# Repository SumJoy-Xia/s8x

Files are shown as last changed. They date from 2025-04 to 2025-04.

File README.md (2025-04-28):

# s8x
open source H87/H88 and infinite875 PCB made by sumjoy
开源H87/H88和infinite875 PCB

kicad preview
kicad预览图




firmware to be updated, stay tuned
固件后续更新

PYG.step is the step file of PCB which represents the 3d model of PCB
in case u need it for drawing keyboard cases
PYG.step是PCB的模型
为了方便大家画键盘

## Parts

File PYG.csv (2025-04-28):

Reference | Value | Footprint
C1,C7 | 10uF | Capacitor_SMD:C_0805_2012Metric
C2,C3,C4,C5,C6 | 100nF | Capacitor_SMD:C_0805_2012Metric
C8 | 0.1uF | Capacitor_SMD:C_0805_2012Metric
D1,D2,D3,D4,D5,D6,D7,D8,D9,D10,D11,D12,D13,D14,D15,D16,D17,D18,D19,D20,D21,D22,D23,D24,D25,D26,D27,D28,D29,D30,D31,D32,D33,D34,D35,D36,D37,D38,D39,D40,D41,D42,D43,D44,D45,D46,D47,D48,D49,D50,D51,D52,D53,D54,D55,D56,D57,D58,D59,D60,D61,D62,D63,D64,D65,D66,D67,D68,D69,D70,D71,D72,D73,D74,D75,D76,D77,D78,D79,D80,D81,D82,D83,D84,D85,D86,D87,D88,D89,D90,D91,D92 | D_Small | Diode_SMD:D_0805_2012Metric
F1 | 500mA | Fuse:Fuse_1206_3216Metric
J1 | Conn_01x04 | Connector_JST:JST_SH_SM04B-SRSS-TB_1x04-1MP_P1.00mm_Horizontal
J3 | USB_C_Receptacle_USB2.0 | Connector_USB:USB_C_Receptacle_HRO_TYPE-C-31-M-12
R1,R4 | 10k | Resistor_SMD:R_0805_2012Metric
R2,R3 | 5.1k | Resistor_SMD:R_0805_2012Metric
R5,R6 | 1k | Resistor_SMD:R_0805_2012Metric
RESET1 | SW_SPST | Button_Switch_SMD:SW_SPST_TL3342
U1 | STM32F072CBT6 | Package_QFP:LQFP-48_7x7mm_P0.5mm
U2 | PRTR5V0U2X | Package_TO_SOT_SMD:SOT-143
U3 | XC6206PxxxMR-Regulator_Linear | Package_TO_SOT_SMD:SOT-23

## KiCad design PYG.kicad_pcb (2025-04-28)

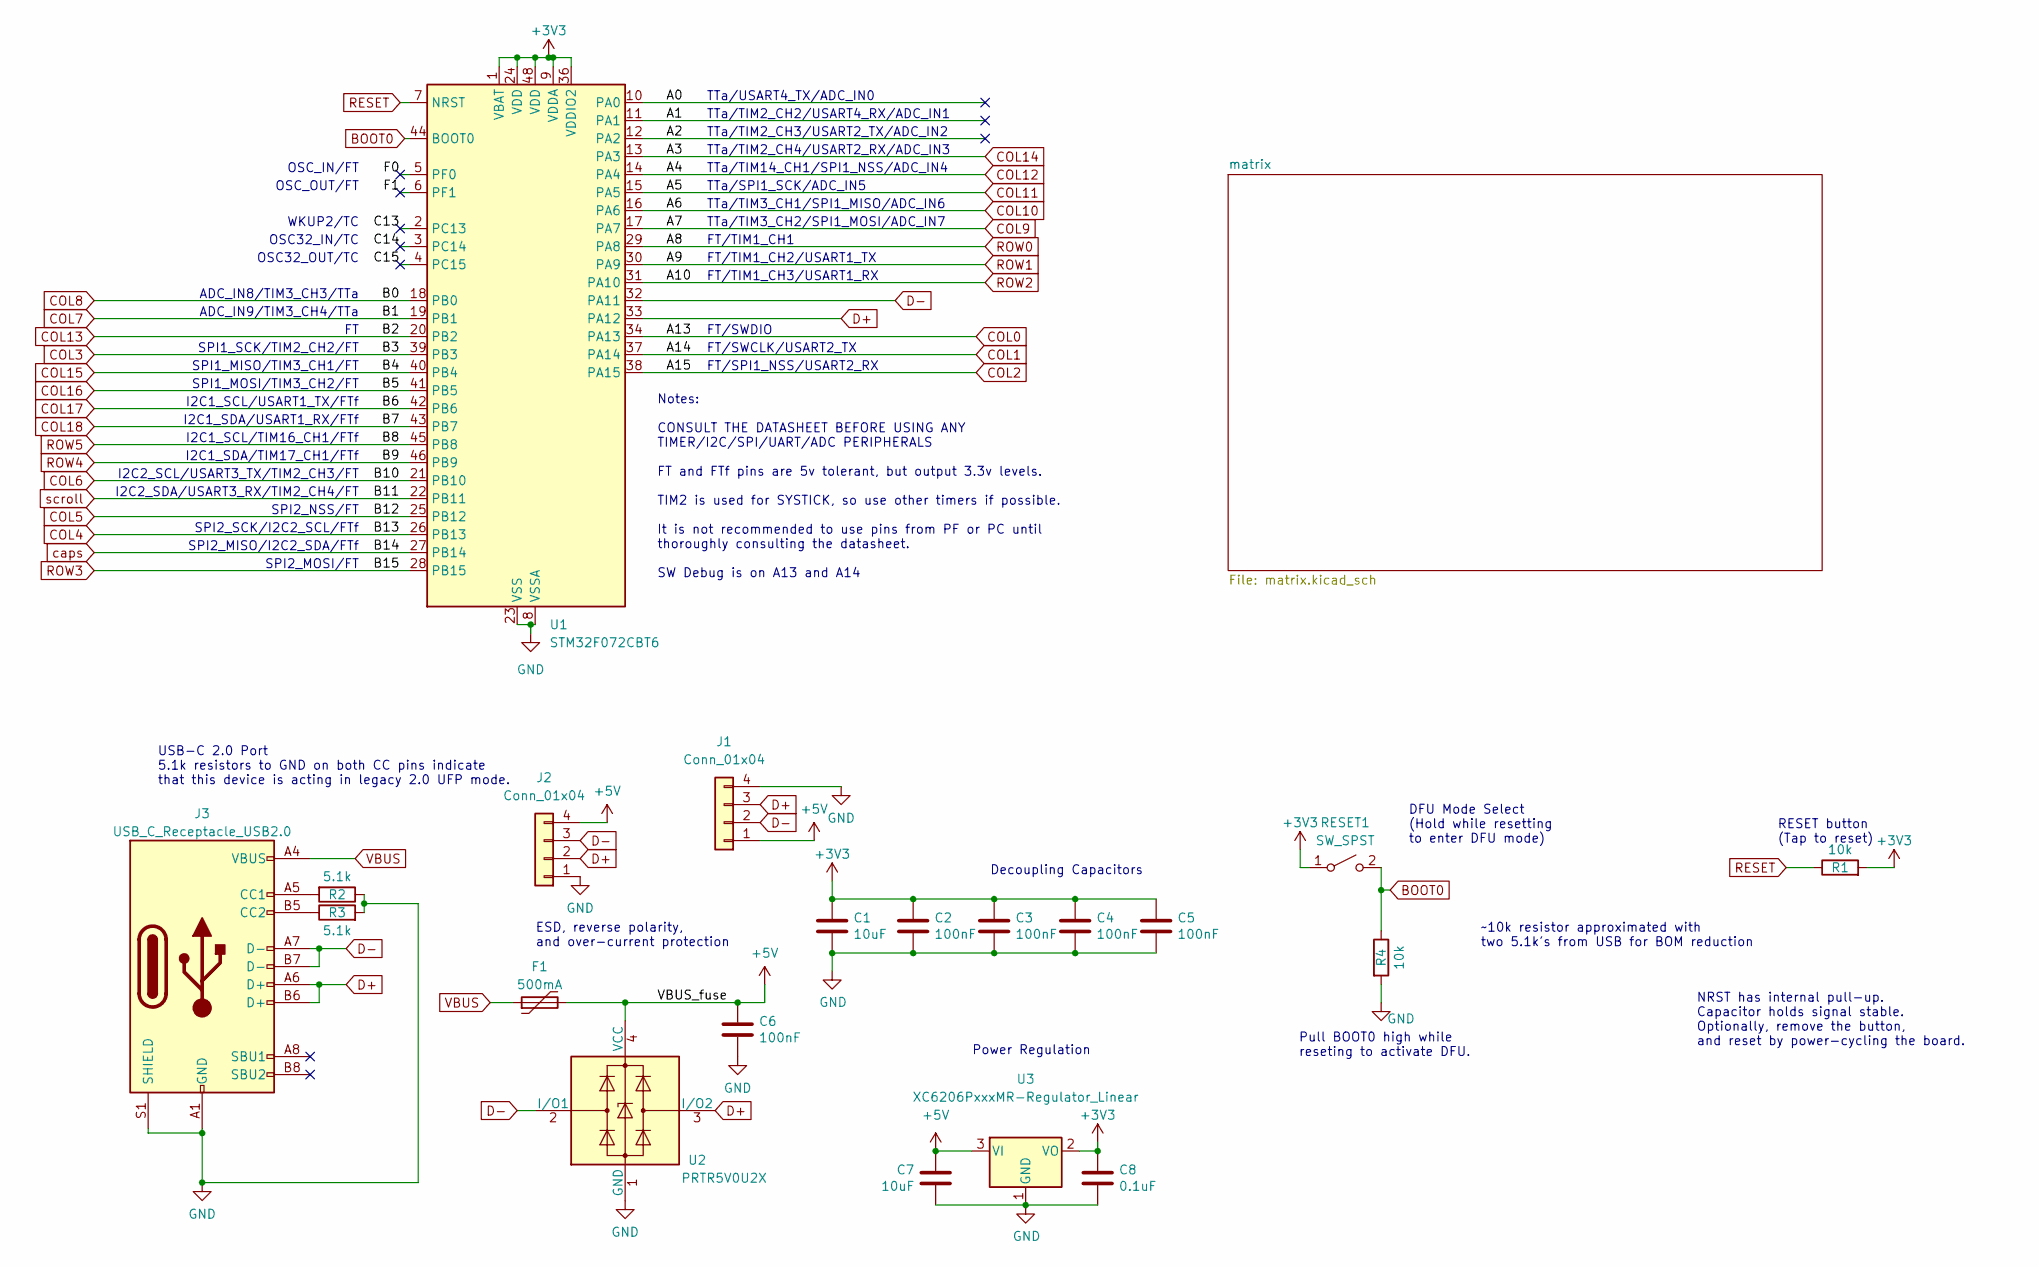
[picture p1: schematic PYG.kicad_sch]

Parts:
C1, C7: 10uF; C_0805_2012Metric; LCSC C307331
C2, C3, C4, C5, C6: 100nF; C_0805_2012Metric; LCSC C307331
C8: 0.1uF; C_0805_2012Metric; LCSC C307331
F1: 500mA; Fuse_1206_3216Metric; LCSC C135341
J1: Conn_01x04; JST_SH_SM04B-SRSS-TB_1x04-1MP_P1.00mm_Horizontal
J2: Conn_01x04; PinHeader_1x04_P2.54mm_Vertical
J3: USB_C_Receptacle_USB2.0; USB_C_Receptacle_HRO_TYPE-C-31-M-12; JlcRotOffset 180
R1, R4: 10k; R_0805_2012Metric
R2, R3: 5.1k; R_0805_2012Metric
RESET1: SW_SPST; SW_SPST_TL3342
U1: STM32F072CBT6; LQFP-48_7x7mm_P0.5mm; JlcRotOffset 90
U2: PRTR5V0U2X; SOT-143; LCSC C2827688
U3: XC6206PxxxMR-Regulator_Linear; SOT-23; LCSC C5446

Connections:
+3V3: C1.1, C2.1, C3.1, C4.1, C5.1, C8.1, R1.2, RESET1.1 (A), U1.1 (VBAT), U1.9 (VDDA), U1.24 (VDD), U1.36 (VDDIO2), U1.48 (VDD), U3.2 (VO)
+5V: C6.1, C7.1, F1.2, J1.1, J2.4, U2.4 (VCC), U3.3 (VI); also elsewhere on the board
/A0: U1.10 (PA0)
/A1: U1.11 (PA1)
/A2: U1.12 (PA2)
/C13: U1.2 (PC13)
/C14: U1.3 (PC14)
/C15: U1.4 (PC15)
/F0: U1.5 (PF0)
/F1: U1.6 (PF1)
BOOT0: R4.1, RESET1.2 (B), U1.44 (BOOT0)
COL0: U1.34 (PA13); also elsewhere on the board
COL1: U1.37 (PA14); also elsewhere on the board
COL2: U1.38 (PA15); also elsewhere on the board
COL3: U1.39 (PB3); also elsewhere on the board
COL4: U1.26 (PB13); also elsewhere on the board
COL5: U1.25 (PB12); also elsewhere on the board
COL6: U1.21 (PB10); also elsewhere on the board
COL7: U1.19 (PB1); also elsewhere on the board
COL8: U1.18 (PB0); also elsewhere on the board
COL9: U1.17 (PA7); also elsewhere on the board
COL10: U1.16 (PA6); also elsewhere on the board
COL11: U1.15 (PA5); also elsewhere on the board
COL12: U1.14 (PA4); also elsewhere on the board
COL13: U1.20 (PB2); also elsewhere on the board
COL14: U1.13 (PA3); also elsewhere on the board
COL15: U1.40 (PB4); also elsewhere on the board
COL16: U1.41 (PB5); also elsewhere on the board
COL17: U1.42 (PB6); also elsewhere on the board
COL18: U1.43 (PB7); also elsewhere on the board
D+: J1.3, J2.2, J3.A6 (D+), J3.B6 (D+), U1.33 (PA12), U2.3 (I/O2)
D-: J1.2, J2.3, J3.A7 (D-), J3.B7 (D-), U1.32 (PA11), U2.2 (I/O1)
GND: C1.2, C2.2, C3.2, C4.2, C5.2, C6.2, C7.2, C8.2, J1.4, J2.1, J3.A1 (GND), J3.A12 (GND), J3.B1 (GND), J3.B12 (GND), J3.S1 (SHIELD), R2.1, R3.2, R4.2, U1.8 (VSSA), U1.23 (VSS), U1.35 (VSS), U1.47 (VSS), U2.1 (GND), U3.1 (GND)
unnamed: J3.A5 (CC1), R2.2
unnamed: J3.B5 (CC2), R3.1
RESET: R1.1, U1.7 (NRST)
ROW0: U1.29 (PA8); also elsewhere on the board
ROW1: U1.30 (PA9); also elsewhere on the board
ROW2: U1.31 (PA10); also elsewhere on the board
ROW3: U1.28 (PB15); also elsewhere on the board
ROW4: U1.46 (PB9); also elsewhere on the board
ROW5: U1.45 (PB8); also elsewhere on the board
VBUS: F1.1, J3.A4 (VBUS), J3.A9 (VBUS), J3.B4 (VBUS), J3.B9 (VBUS)
caps: U1.27 (PB14); also elsewhere on the board
scroll: U1.22 (PB11); also elsewhere on the board

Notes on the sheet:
SPI1_SCK/TIM2_CH2/FT
SPI2_MISO/I2C2_SDA/FTf
SPI1_MOSI/TIM3_CH2/FT
Notes: CONSULT THE DATASHEET BEFORE USING ANY TIMER/I2C/SPI/UART/ADC PERIPHERALS FT and FTf pins are 5v tolerant, but output 3.3v levels. TIM2 is used for SYSTICK, so use other timers if possible. It is not recommended to use pins from PF or PC until thoroughly consulting the datasheet. SW Debug is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
TTa/TIM3_CH2/SPI1_MOSI/ADC_IN7
FT/TIM1_CH3/USART1_RX
SPI2_MOSI/FT
I2C1_SDA/USART1_RX/FTf
FT/TIM1_CH1
OSC32_OUT/TC
I2C2_SDA/USART3_RX/TIM2_CH4/FT
SPI2_SCK/I2C2_SCL/FTf
OSC_OUT/FT
SPI2_NSS/FT
TTa/TIM3_CH1/SPI1_MISO/ADC_IN6
SPI1_MISO/TIM3_CH1/FT
I2C1_SDA/TIM17_CH1/FTf
I2C2_SCL/USART3_TX/TIM2_CH3/FT
I2C1_SCL/TIM16_CH1/FTf
ADC_IN8/TIM3_CH3/TTa
WKUP2/TC
TTa/TIM2_CH3/USART2_TX/ADC_IN2
TTa/TIM14_CH1/SPI1_NSS/ADC_IN4
NRST has internal pull-up. Capacitor holds signal stable. Optionally, remove the button, and reset by power-cycling the board.
DFU Mode Select (Hold while resetting to enter DFU mode)
ESD, reverse polarity, and over-current protection
FT/SPI1_NSS/USART2_RX
~10k resistor approximated with two 5.1k's from USB for BOM reduction
FT/SWDIO
TTa/TIM2_CH4/USART2_RX/ADC_IN3
TTa/USART4_TX/ADC_IN0
USB-C 2.0 Port 5.1k resistors to GND on both CC pins indicate that this device is acting in legacy 2.0 UFP mode.
RESET button (Tap to reset)
ADC_IN9/TIM3_CH4/TTa
TTa/SPI1_SCK/ADC_IN5
FT/TIM1_CH2/USART1_TX
Power Regulation
OSC_IN/FT
TTa/TIM2_CH2/USART4_RX/ADC_IN1
Decoupling Capacitors

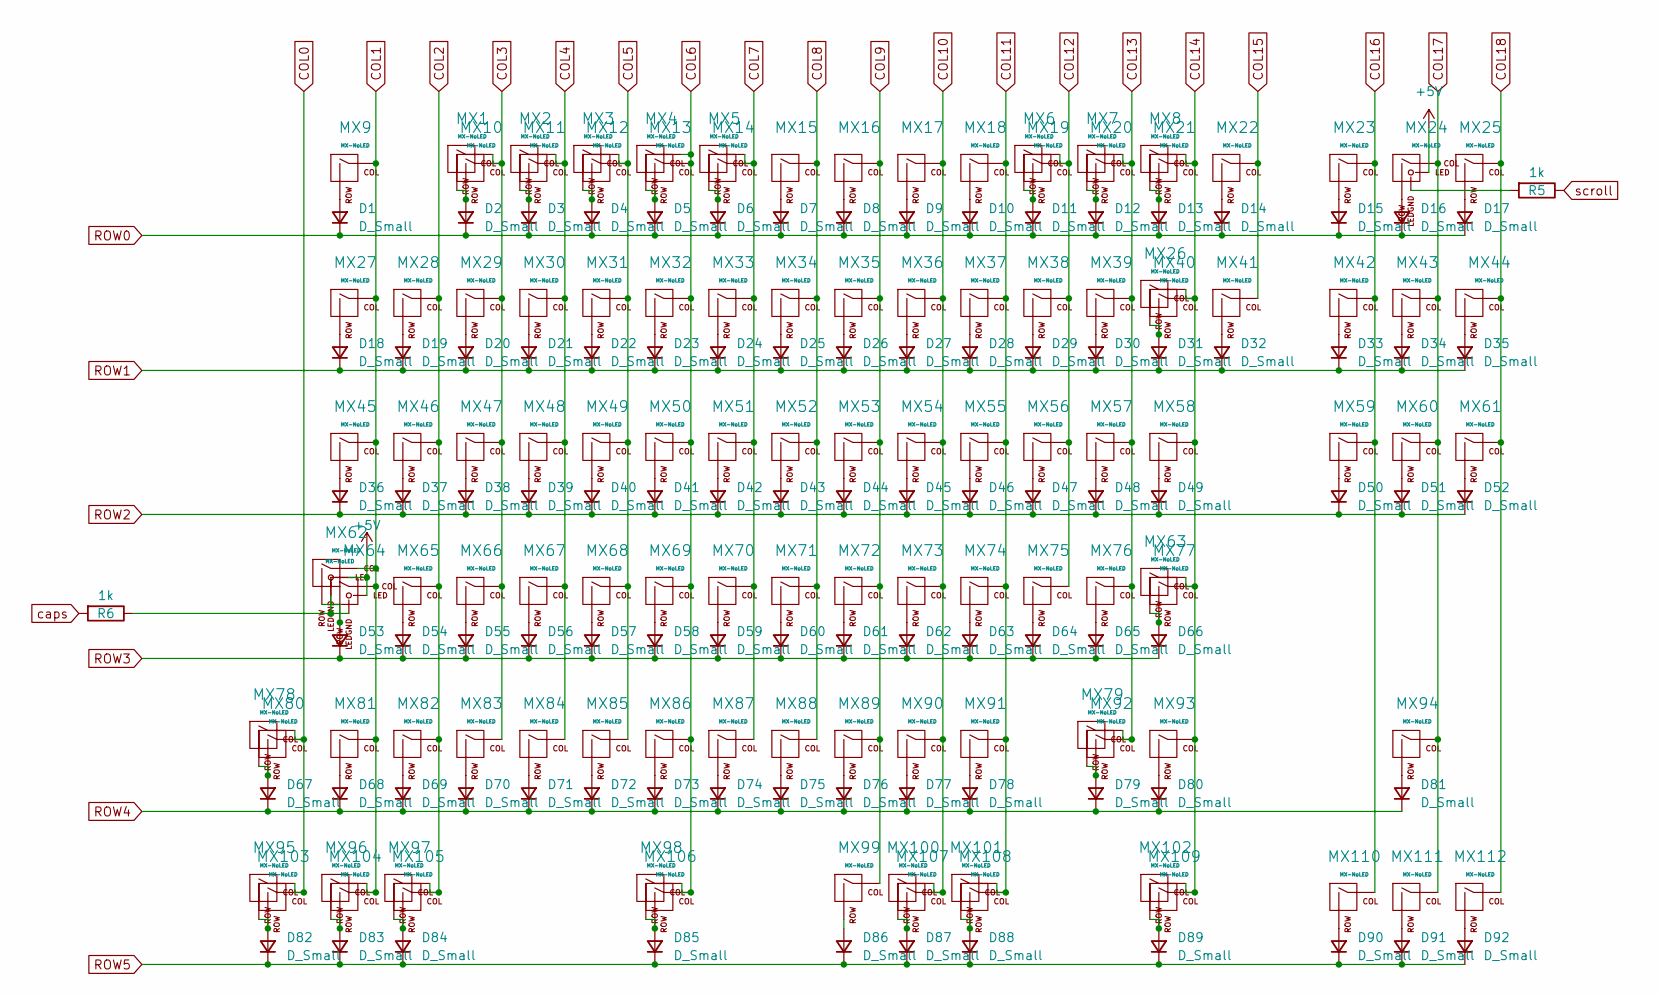
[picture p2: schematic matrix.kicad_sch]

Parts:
D1, D2, D3, D4, D5, D6, D7, D8, D9, D10, D11, D12, D13, D14, D15, D16, D17, D18, D19, D20, D21, D22, D23, D24, D25, D26, D27, D28, D29, D30, D31, D32, D33, D34, D35, D36, D37, D38, D39, D40, D41, D42, D43, D44, D45, D46, D47, D48, D49, D50, D51, D52, D53, D54, D55, D56, D57, D58, D59, D60, D61, D62, D63, D64, D65, D66, D67, D68, D69, D70, D71, D72, D73, D74, D75, D76, D77, D78, D79, D80, D81, D82, D83, D84, D85, D86, D87, D88, D89, D90, D91, D92: D_Small; D_0805_2012Metric
MX1, MX2, MX3, MX4, MX5, MX6, MX7, MX8, MX9, MX10, MX11, MX12, MX13, MX14, MX15, MX16, MX17, MX18, MX19, MX20, MX21, MX22, MX23, MX25, MX26, MX27, MX28, MX29, MX30, MX31, MX32, MX33, MX34, MX35, MX36, MX37, MX38, MX39, MX41, MX42, MX43, MX44, MX46, MX47, MX48, MX49, MX50, MX51, MX52, MX53, MX54, MX55, MX56, MX57, MX59, MX60, MX61, MX65, MX66, MX67, MX68, MX69, MX70, MX71, MX72, MX73, MX74, MX75, MX76, MX81, MX82, MX83, MX84, MX85, MX86, MX87, MX88, MX89, MX90, MX91, MX93, MX94, MX104, MX108, MX110, MX111, MX112: MX-NoLED; MXOnly-1U-NoLED
MX24: MX-NoLED; MXOnly-1U
MX40: MX-NoLED; MXOnly-2U-NoLED
MX45, MX58, MX103, MX105, MX107, MX109: MX-NoLED; MXOnly-1.5U-NoLED
MX62: MX-NoLED; MXOnly-1.75U-FLIPPED
MX63: MX-NoLED; MXOnly-ISO-ReversedStabilizers-NoLED
MX64: MX-NoLED; MXOnly-1.75U-STEP1.25
MX77, MX80: MX-NoLED; MXOnly-2.25U-NoLED
MX78, MX95, MX96, MX97, MX99, MX100, MX101, MX102: MX-NoLED; MXOnly-1.25U-NoLED
MX79: MX-NoLED; MXOnly-1.75U-NoLED
MX92: MX-NoLED; MXOnly-2.75U-NoLED
MX98: MX-NoLED; MXOnly-6.25U-ReversedStabilizers-NoLED
MX106: MX-NoLED; MXOnly-7U-ReversedStabilizers-NoLED
R5, R6: 1k; R_0805_2012Metric

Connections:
+5V: MX24.3 (LED), MX62.3 (LED), MX64.3 (LED); also elsewhere on the board
COL0: MX78.1 (COL), MX80.1 (COL), MX95.1 (COL), MX103.1 (COL); also elsewhere on the board
COL1: MX9.1 (COL), MX27.1 (COL), MX45.1 (COL), MX62.1 (COL), MX64.1 (COL), MX81.1 (COL), MX96.1 (COL), MX104.1 (COL); also elsewhere on the board
COL2: MX28.1 (COL), MX46.1 (COL), MX65.1 (COL), MX82.1 (COL), MX97.1 (COL), MX105.1 (COL); also elsewhere on the board
COL3: MX1.1 (COL), MX10.1 (COL), MX29.1 (COL), MX47.1 (COL), MX66.1 (COL), MX83.1 (COL); also elsewhere on the board
COL4: MX2.1 (COL), MX11.1 (COL), MX30.1 (COL), MX48.1 (COL), MX67.1 (COL), MX84.1 (COL); also elsewhere on the board
COL5: MX3.1 (COL), MX12.1 (COL), MX31.1 (COL), MX49.1 (COL), MX68.1 (COL), MX85.1 (COL); also elsewhere on the board
COL6: MX4.1 (COL), MX13.1 (COL), MX32.1 (COL), MX50.1 (COL), MX69.1 (COL), MX86.1 (COL), MX98.1 (COL), MX106.1 (COL); also elsewhere on the board
COL7: MX5.1 (COL), MX14.1 (COL), MX33.1 (COL), MX51.1 (COL), MX70.1 (COL), MX87.1 (COL); also elsewhere on the board
COL8: MX15.1 (COL), MX34.1 (COL), MX52.1 (COL), MX71.1 (COL), MX88.1 (COL); also elsewhere on the board
COL9: MX16.1 (COL), MX35.1 (COL), MX53.1 (COL), MX72.1 (COL), MX89.1 (COL), MX99.1 (COL); also elsewhere on the board
COL10: MX17.1 (COL), MX36.1 (COL), MX54.1 (COL), MX73.1 (COL), MX90.1 (COL), MX100.1 (COL), MX107.1 (COL); also elsewhere on the board
COL11: MX18.1 (COL), MX37.1 (COL), MX55.1 (COL), MX74.1 (COL), MX91.1 (COL), MX101.1 (COL), MX108.1 (COL); also elsewhere on the board
COL12: MX6.1 (COL), MX19.1 (COL), MX38.1 (COL), MX56.1 (COL), MX75.1 (COL); also elsewhere on the board
COL13: MX7.1 (COL), MX20.1 (COL), MX39.1 (COL), MX57.1 (COL), MX76.1 (COL), MX79.1 (COL), MX92.1 (COL); also elsewhere on the board
COL14: MX8.1 (COL), MX21.1 (COL), MX26.1 (COL), MX40.1 (COL), MX58.1 (COL), MX63.1 (COL), MX77.1 (COL), MX93.1 (COL), MX102.1 (COL), MX109.1 (COL); also elsewhere on the board
COL15: MX22.1 (COL), MX41.1 (COL); also elsewhere on the board
COL16: MX23.1 (COL), MX42.1 (COL), MX59.1 (COL), MX110.1 (COL); also elsewhere on the board
COL17: MX24.1 (COL), MX43.1 (COL), MX60.1 (COL), MX94.1 (COL), MX111.1 (COL); also elsewhere on the board
COL18: MX25.1 (COL), MX44.1 (COL), MX61.1 (COL), MX112.1 (COL); also elsewhere on the board
unnamed: D1.2 (A), MX9.2 (ROW)
unnamed: D2.2 (A), MX1.2 (ROW), MX10.2 (ROW)
unnamed: D3.2 (A), MX2.2 (ROW), MX11.2 (ROW)
unnamed: D4.2 (A), MX3.2 (ROW), MX12.2 (ROW)
unnamed: D5.2 (A), MX4.2 (ROW), MX13.2 (ROW)
unnamed: D6.2 (A), MX5.2 (ROW), MX14.2 (ROW)
unnamed: D7.2 (A), MX15.2 (ROW)
unnamed: D8.2 (A), MX16.2 (ROW)
unnamed: D9.2 (A), MX17.2 (ROW)
unnamed: D10.2 (A), MX18.2 (ROW)
unnamed: D11.2 (A), MX6.2 (ROW), MX19.2 (ROW)
unnamed: D12.2 (A), MX7.2 (ROW), MX20.2 (ROW)
unnamed: D13.2 (A), MX8.2 (ROW), MX21.2 (ROW)
unnamed: D14.2 (A), MX22.2 (ROW)
unnamed: D15.2 (A), MX23.2 (ROW)
unnamed: D16.2 (A), MX24.2 (ROW)
unnamed: D17.2 (A), MX25.2 (ROW)
unnamed: D18.2 (A), MX27.2 (ROW)
unnamed: D19.2 (A), MX28.2 (ROW)
unnamed: D20.2 (A), MX29.2 (ROW)
unnamed: D21.2 (A), MX30.2 (ROW)
unnamed: D22.2 (A), MX31.2 (ROW)
unnamed: D23.2 (A), MX32.2 (ROW)
unnamed: D24.2 (A), MX33.2 (ROW)
unnamed: D25.2 (A), MX34.2 (ROW)
unnamed: D26.2 (A), MX35.2 (ROW)
unnamed: D27.2 (A), MX36.2 (ROW)
unnamed: D28.2 (A), MX37.2 (ROW)
unnamed: D29.2 (A), MX38.2 (ROW)
unnamed: D30.2 (A), MX39.2 (ROW)
unnamed: D31.2 (A), MX26.2 (ROW), MX40.2 (ROW)
unnamed: D32.2 (A), MX41.2 (ROW)
unnamed: D33.2 (A), MX42.2 (ROW)
unnamed: D34.2 (A), MX43.2 (ROW)
unnamed: D35.2 (A), MX44.2 (ROW)
unnamed: D36.2 (A), MX45.2 (ROW)
unnamed: D37.2 (A), MX46.2 (ROW)
unnamed: D38.2 (A), MX47.2 (ROW)
unnamed: D39.2 (A), MX48.2 (ROW)
unnamed: D40.2 (A), MX49.2 (ROW)
unnamed: D41.2 (A), MX50.2 (ROW)
unnamed: D42.2 (A), MX51.2 (ROW)
unnamed: D43.2 (A), MX52.2 (ROW)
unnamed: D44.2 (A), MX53.2 (ROW)
unnamed: D45.2 (A), MX54.2 (ROW)
unnamed: D46.2 (A), MX55.2 (ROW)
unnamed: D47.2 (A), MX56.2 (ROW)
unnamed: D48.2 (A), MX57.2 (ROW)
unnamed: D49.2 (A), MX58.2 (ROW)
unnamed: D50.2 (A), MX59.2 (ROW)
unnamed: D51.2 (A), MX60.2 (ROW)
unnamed: D52.2 (A), MX61.2 (ROW)
unnamed: D53.2 (A), MX62.2 (ROW), MX64.2 (ROW)
unnamed: D54.2 (A), MX65.2 (ROW)
unnamed: D55.2 (A), MX66.2 (ROW)
unnamed: D56.2 (A), MX67.2 (ROW)
unnamed: D57.2 (A), MX68.2 (ROW)
unnamed: D58.2 (A), MX69.2 (ROW)
unnamed: D59.2 (A), MX70.2 (ROW)
unnamed: D60.2 (A), MX71.2 (ROW)
unnamed: D61.2 (A), MX72.2 (ROW)
unnamed: D62.2 (A), MX73.2 (ROW)
unnamed: D63.2 (A), MX74.2 (ROW)
unnamed: D64.2 (A), MX75.2 (ROW)
unnamed: D65.2 (A), MX76.2 (ROW)
unnamed: D66.2 (A), MX63.2 (ROW), MX77.2 (ROW)
unnamed: D67.2 (A), MX78.2 (ROW), MX80.2 (ROW)
unnamed: D68.2 (A), MX81.2 (ROW)
unnamed: D69.2 (A), MX82.2 (ROW)
unnamed: D70.2 (A), MX83.2 (ROW)
unnamed: D71.2 (A), MX84.2 (ROW)
unnamed: D72.2 (A), MX85.2 (ROW)
unnamed: D73.2 (A), MX86.2 (ROW)
unnamed: D74.2 (A), MX87.2 (ROW)
unnamed: D75.2 (A), MX88.2 (ROW)
unnamed: D76.2 (A), MX89.2 (ROW)
unnamed: D77.2 (A), MX90.2 (ROW)
unnamed: D78.2 (A), MX91.2 (ROW)
unnamed: D79.2 (A), MX79.2 (ROW), MX92.2 (ROW)
unnamed: D80.2 (A), MX93.2 (ROW)
unnamed: D81.2 (A), MX94.2 (ROW)
unnamed: D82.2 (A), MX95.2 (ROW), MX103.2 (ROW)
unnamed: D83.2 (A), MX96.2 (ROW), MX104.2 (ROW)
unnamed: D84.2 (A), MX97.2 (ROW), MX105.2 (ROW)
unnamed: D85.2 (A), MX98.2 (ROW), MX106.2 (ROW)
unnamed: D86.2 (A), MX99.2 (ROW)
unnamed: D87.2 (A), MX100.2 (ROW), MX107.2 (ROW)
unnamed: D88.2 (A), MX101.2 (ROW), MX108.2 (ROW)
unnamed: D89.2 (A), MX102.2 (ROW), MX109.2 (ROW)
unnamed: D90.2 (A), MX110.2 (ROW)
unnamed: D91.2 (A), MX111.2 (ROW)
unnamed: D92.2 (A), MX112.2 (ROW)
unnamed: MX24.4 (LEDGND), R5.2
unnamed: MX62.4 (LEDGND), MX64.4 (LEDGND), R6.1
ROW0: D1.1 (K), D2.1 (K), D3.1 (K), D4.1 (K), D5.1 (K), D6.1 (K), D7.1 (K), D8.1 (K), D9.1 (K), D10.1 (K), D11.1 (K), D12.1 (K), D13.1 (K), D14.1 (K), D15.1 (K), D16.1 (K), D17.1 (K); also elsewhere on the board
ROW1: D18.1 (K), D19.1 (K), D20.1 (K), D21.1 (K), D22.1 (K), D23.1 (K), D24.1 (K), D25.1 (K), D26.1 (K), D27.1 (K), D28.1 (K), D29.1 (K), D30.1 (K), D31.1 (K), D32.1 (K), D33.1 (K), D34.1 (K), D35.1 (K); also elsewhere on the board
ROW2: D36.1 (K), D37.1 (K), D38.1 (K), D39.1 (K), D40.1 (K), D41.1 (K), D42.1 (K), D43.1 (K), D44.1 (K), D45.1 (K), D46.1 (K), D47.1 (K), D48.1 (K), D49.1 (K), D50.1 (K), D51.1 (K), D52.1 (K); also elsewhere on the board
ROW3: D53.1 (K), D54.1 (K), D55.1 (K), D56.1 (K), D57.1 (K), D58.1 (K), D59.1 (K), D60.1 (K), D61.1 (K), D62.1 (K), D63.1 (K), D64.1 (K), D65.1 (K), D66.1 (K); also elsewhere on the board
ROW4: D67.1 (K), D68.1 (K), D69.1 (K), D70.1 (K), D71.1 (K), D72.1 (K), D73.1 (K), D74.1 (K), D75.1 (K), D76.1 (K), D77.1 (K), D78.1 (K), D79.1 (K), D80.1 (K), D81.1 (K); also elsewhere on the board
ROW5: D82.1 (K), D83.1 (K), D84.1 (K), D85.1 (K), D86.1 (K), D87.1 (K), D88.1 (K), D89.1 (K), D90.1 (K), D91.1 (K), D92.1 (K); also elsewhere on the board
caps: R6.2; also elsewhere on the board
scroll: R5.1; also elsewhere on the board

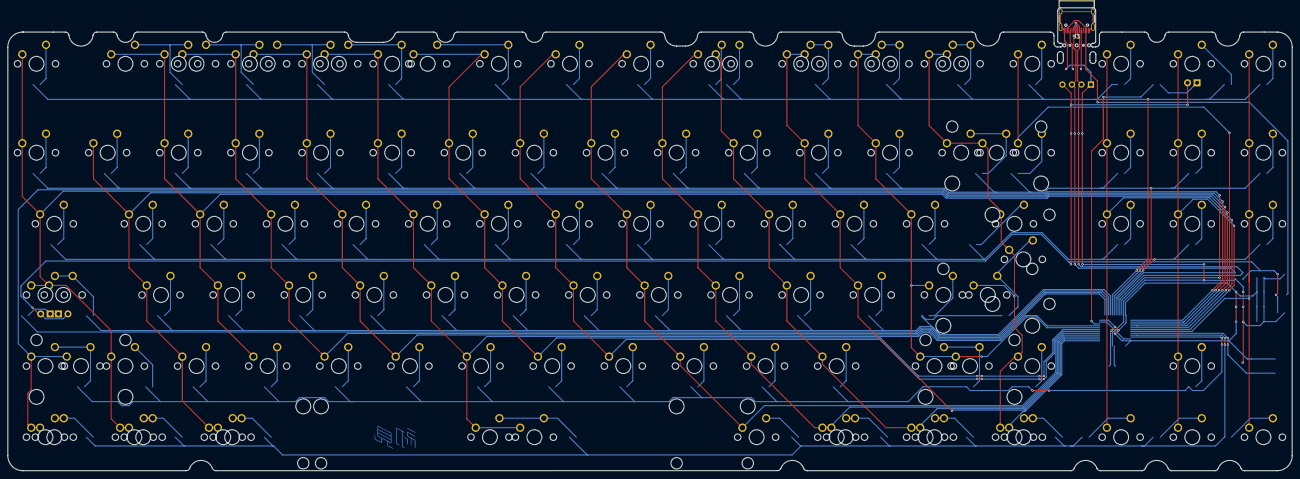
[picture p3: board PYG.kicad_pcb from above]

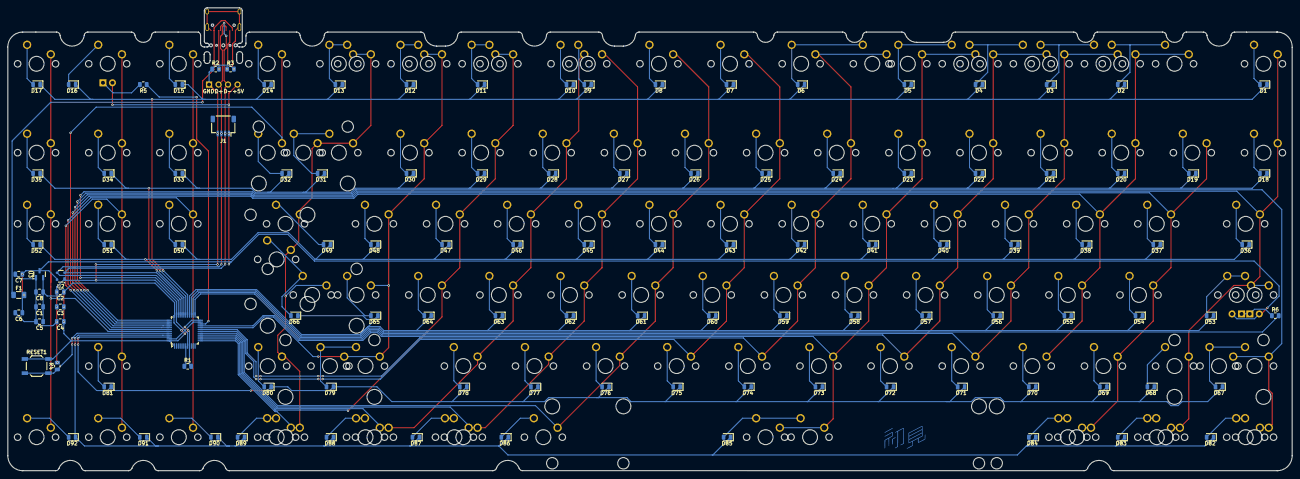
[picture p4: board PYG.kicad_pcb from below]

Board: 2 copper layers, 344.0 x 124.0 mm, 226 parts (112 on the bottom side), 131 nets.
